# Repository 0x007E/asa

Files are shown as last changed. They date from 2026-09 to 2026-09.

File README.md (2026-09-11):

  

# `ASA` - Audio Signal Amplifier

The `ASA` is a board with an [LM386](#additional-information) or any other audio signal amplifier. The board itself can be driven with a voltage between `5-12V`. It adds and amplifies the given  input signal(s) with a gain between `~50-200` to a connected speaker. If the supply of the board is available the `green` led is `on`. The board itself provides a reverse polarity protection.

| Experience | Level |
|:---|:-----:|
| Soldering | ?% |

# Downloads

| Type | File | Description |
|:---:|:---:|:---|
| Schematic | [pdf](https://github.com/0x007E/asa/releases/latest/download/schematic.pdf) / [cadlab](https://cadlab.io/project/30571/main/files) | Schematic files |
| Board | [pdf](https://github.com/0x007E/asa/releases/latest/download/pcb.pdf) / [cadlab](https://cadlab.io/project/30571/main/files) | Board file |
| Drill | [pdf](https://github.com/0x007E/asa/releases/latest/download/drill.pdf) | Drill file |
| BoM | [xlsx](https://github.com/0x007E/asa/releases/latest/download/bom.xlsx) / [html](https://github.com/0x007E/asa/releases/latest/download/ibom.html) | Bill of Material as Excel/interactive HTML |
| PCB | [zip](https://github.com/0x007E/asa/releases/latest/download/kicad.zip) / [tar](https://github.com/0x007E/asa/releases/latest/download/kicad.tar.gz) | KiCAD/Gerber/BoM/Drill files |

# Hardware

The pcb is created with `KiCAD`. All files are built with `github actions` so that they are ready for a production environment.

## PCB

The circuit board is populated on one side. The best way for soldering the `SMD` components is within a vapor phase soldering system and for the `THT` components with a standard system.

### Top Layer

Top Layer

### Bottom Layer

Bottom Layer

# Configuration

The gain of the `ASA` can be set with the `RV2` trimmer. If the trimmer is not solderd the standard gain is around `~20`. If `R7` and `C11` is solder `bass boost` mode is enabled.

# Additional Information

| Type  | Link | Description |
|:---|:---:|:---|
| LM386 | [pdf](https://www.ti.com/lit/ds/symlink/lm386.pdf) | Low Voltage Audio Power Amplifier Datasheet |

---

R. GAECHTER

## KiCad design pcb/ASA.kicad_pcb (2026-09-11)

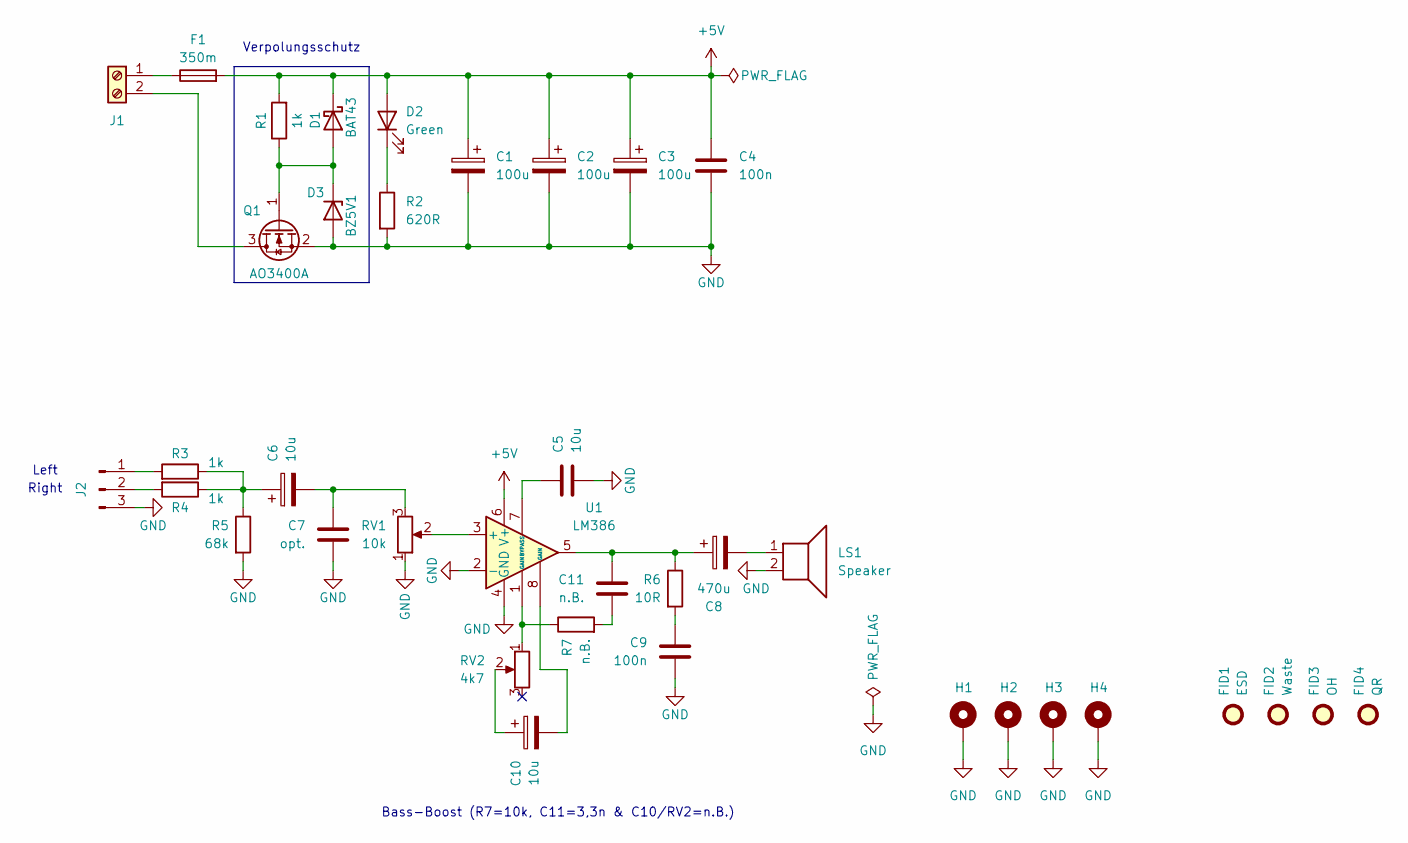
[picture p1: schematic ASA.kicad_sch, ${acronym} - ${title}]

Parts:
C1, C2, C3: 100u; CP_Radial_D5.0mm_P2.00mm
C4, C9: 100n; C_1206_3216Metric
C5: 10u; C_1206_3216Metric
C6, C10: 10u; CP_Elec_4x4.5
C7: opt.; C_1206_3216Metric
C8: 470u; CP_Radial_D8.0mm_P3.50mm
C11: n.B.; C_1206_3216Metric
D1: BAT43; D_MiniMELF
D2: Green; LED_1206_3216Metric
D3: BZ5V1; D_MiniMELF
F1: 350m; Fuse_1206_3216Metric
FID1: ESD; ESD-Logo_6.6x6mm_SilkScreen
FID2: Waste; WEEE-Logo_4.2x6mm_SilkScreen
FID3: OH; OSHW-Logo_5.7x6mm_SilkScreen
FID4: QR; QR_0x007e
H1, H2, H3, H4: MountingHole_Pad; MountingHole_3.2mm_M3_DIN965_Pad
J1: Screw_Terminal_01x02; TerminalBlock_Phoenix_MKDS-1,5-2-5.08_1x02_P5.08mm_Horizont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
J2: Conn_01x03_Pin; PinHeader_1x03_P2.54mm_Vertical
LS1: Speaker; TerminalBlock_Phoenix_MKDS-1,5-2-5.08_1x02_P5.08mm_Horizont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
Q1: AO3400A; SOT-23-3
R1, R3, R4: 1k; R_1206_3216Metric
R2: 620R; R_1206_3216Metric
R5: 68k; R_1206_3216Metric
R6: 10R; R_1206_3216Metric
R7: n.B.; R_1206_3216Metric
RV1: 10k; Potentiometer_Piher_PT-10-V10_Vertical
RV2: 4k7; Potentiometer_Bourns_3296W_Vertical
U1: LM386; DIP-8_W7.62mm_Socket_LongPads

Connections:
+5V: C1.1, C2.1, C3.1, C4.1, D1.1 (K), D2.2 (A), F1.2, R1.2, U1.6 (V+)
GND: C1.2, C2.2, C3.2, C4.2, C5.2, C7.2, C9.2, D3.2 (A), H1.1, H2.1, H3.1, H4.1, J2.3, LS1.2, Q1.2 (S), R2.2, R5.2, RV1.1, U1.2 (-), U1.4 (GND)
unnamed: C6.1, R3.1, R4.1, R5.1
unnamed: C6.2, C7.1, RV1.3
unnamed: C8.2, LS1.1
unnamed: C9.1, R6.2
unnamed: C10.1, RV2.2
unnamed: C10.2, U1.8 (GAIN)
unnamed: C8.1, C11.1, R6.1, U1.5
unnamed: C11.2, R7.2
unnamed: D1.2 (A), D3.1 (K), Q1.1 (G), R1.1
unnamed: D2.1 (K), R2.1
unnamed: F1.1, J1.1
unnamed: J1.2, Q1.3 (D)
unnamed: J2.1, R3.2
unnamed: J2.2, R4.2
unnamed: R7.1, RV2.1, U1.1 (GAIN)
unnamed: RV1.2, U1.3 (+)
unnamed: C5.1, U1.7 (BYPASS)

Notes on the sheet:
Verpolungsschutz
Right
Bass-Boost (R7=10k, C11=3,3n & C10/RV2=n.B.)
Left

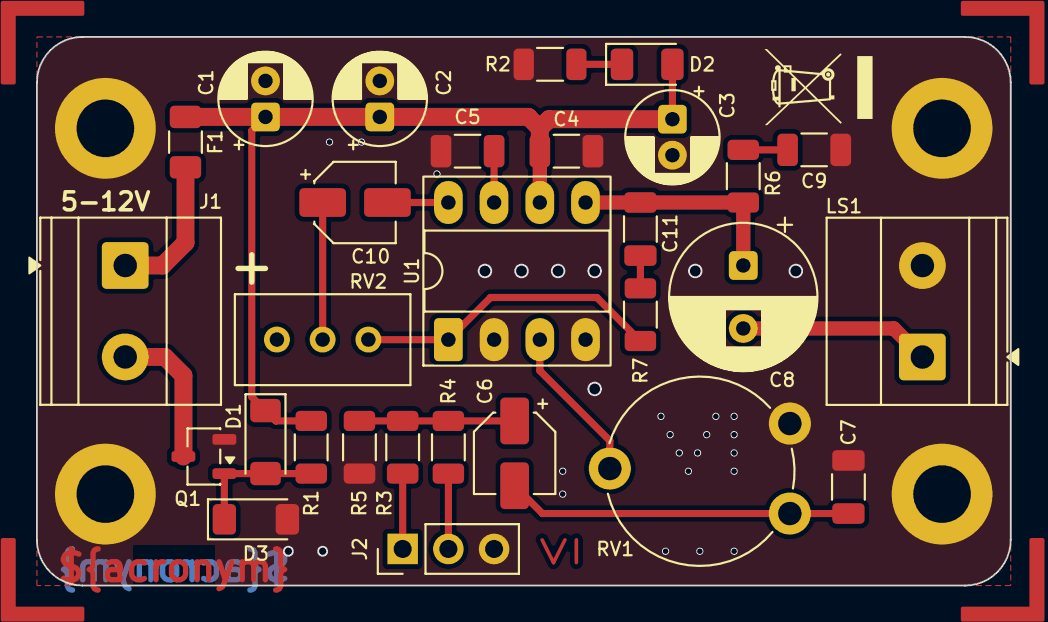
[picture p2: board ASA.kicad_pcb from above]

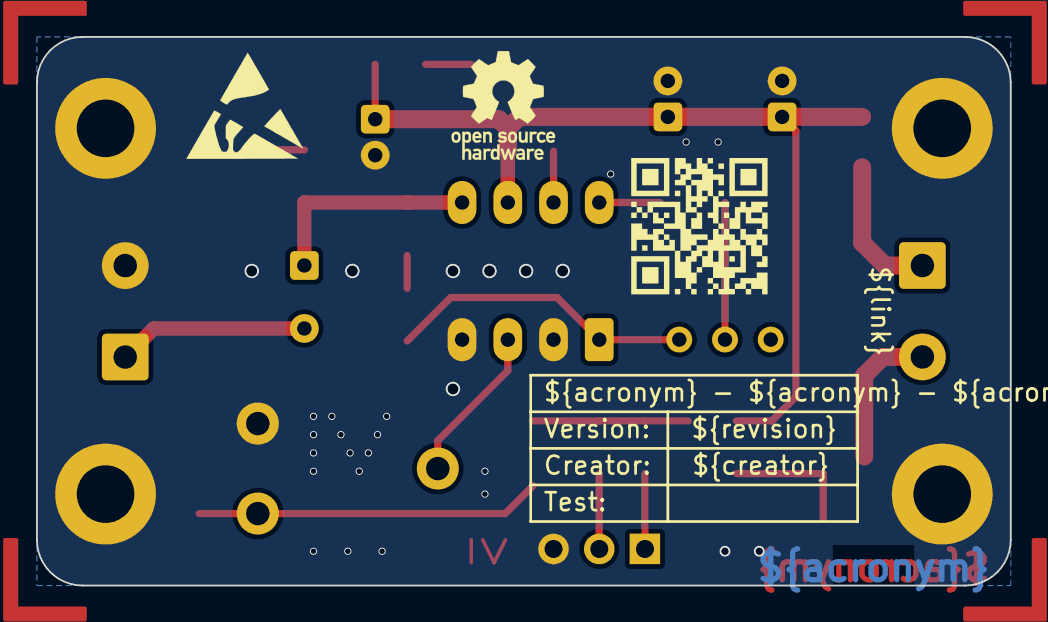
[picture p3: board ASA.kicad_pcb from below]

Board: 2 copper layers, 54.1 x 30.5 mm, 37 parts (3 on the bottom side), 19 nets.

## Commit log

2026-09-11 Add pcb layout
    [ASA.kicad_pcb, ASA.kicad_sch]
2026-09-11 Add bass boost option
    [ASA.kicad_pcb, ASA.kicad_sch]

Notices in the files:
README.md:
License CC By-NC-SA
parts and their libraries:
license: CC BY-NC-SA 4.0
